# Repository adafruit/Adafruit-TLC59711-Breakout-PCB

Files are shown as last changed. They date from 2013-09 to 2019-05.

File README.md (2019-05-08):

# PCB for the Adafruit TLC59711 12-LED PWM breakout board

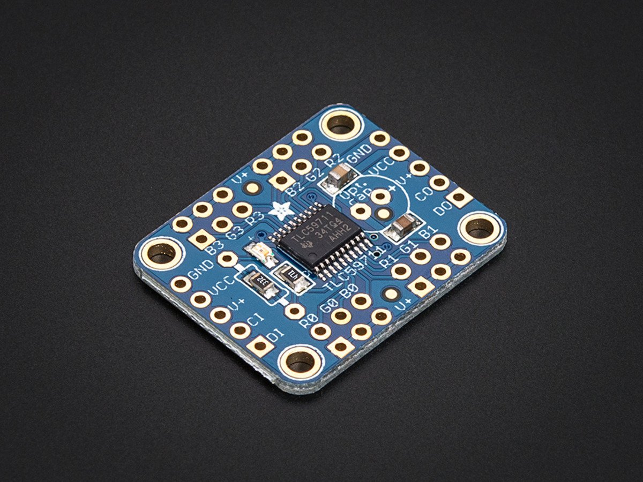
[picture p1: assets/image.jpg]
<a href="http://www.adafruit.com/products/1455"><br/>Click here to purchase one from the Adafruit shop</a>

For all of you out there who want to control 12 channels of PWM, we salute you! We also would like you to check out this breakout board for the TLC59711 PWM driver chip. This chip can control 12 separate channels of 16-bit PWM output. This is the highest-resolution PWM board we've seen! Designed (and ideal) for precision LED control, this board is not good for driving servos. If you need to drive servos, [we have a controller for that over here](http://www.adafruit.com/products/815).

Only two "SPI" pins are required to send data (our Arduino library shows how to to use any digital microcontroller pins). Best of all, the design is completely chainable. As long as there's enough power for all the boards you can chain as many as you'd like, like a little trail of blue PCBs stretching out into the sunset. Each of the 12 outputs are constant-current and open drain. You can drive multiple LEDs in series, with a V+ anode supply of up to 17V. If you want to drive something that requires a digital input, you must use a pullup resistor from the drive pin to your logic level to create the full waveform.

One resistor is used to set the current for each of the outputs, the constant current means that the LED brightness doesn't vary if the power supply dips. We use a 3.3K resistor for about 15mA but you can solder a thru-hole resistor over it if you'd like to change that value. Check the [TLC59711 datasheet](http://www.adafruit.com/datasheets/tlc59711.pdf) for details on resistor-to-current values. There's also a handy on-chip 3.3V regulator which you can use if you need a logic level regulator.

We include a few extras to make this board easy to use: a green power-good LED, four mounting holes and a current-set resistor. A bit of 0.1" header is also included so you can solder it on and plug into a breadboard.

To use: Power V+ with 5-17VDC, and connect ground to the common ground. Then send 3-5V logic SPI data on DIN (data in) and CLK (clock). Our Arduino library will get you started with blinking LEDs, install it and run the example code with the noted pin configuration.

There's a typo in the silkscreen, the second R0 should be R1 - but you knew that already!

## License

Adafruit invests time and resources providing this open source design, 
please support Adafruit and open-source hardware by purchasing 
products from Adafruit!

Designed by Adafruit Industries.  
Creative Commons Attribution, Share-Alike license, check license.txt for more information
All text above must be included in any redistribution

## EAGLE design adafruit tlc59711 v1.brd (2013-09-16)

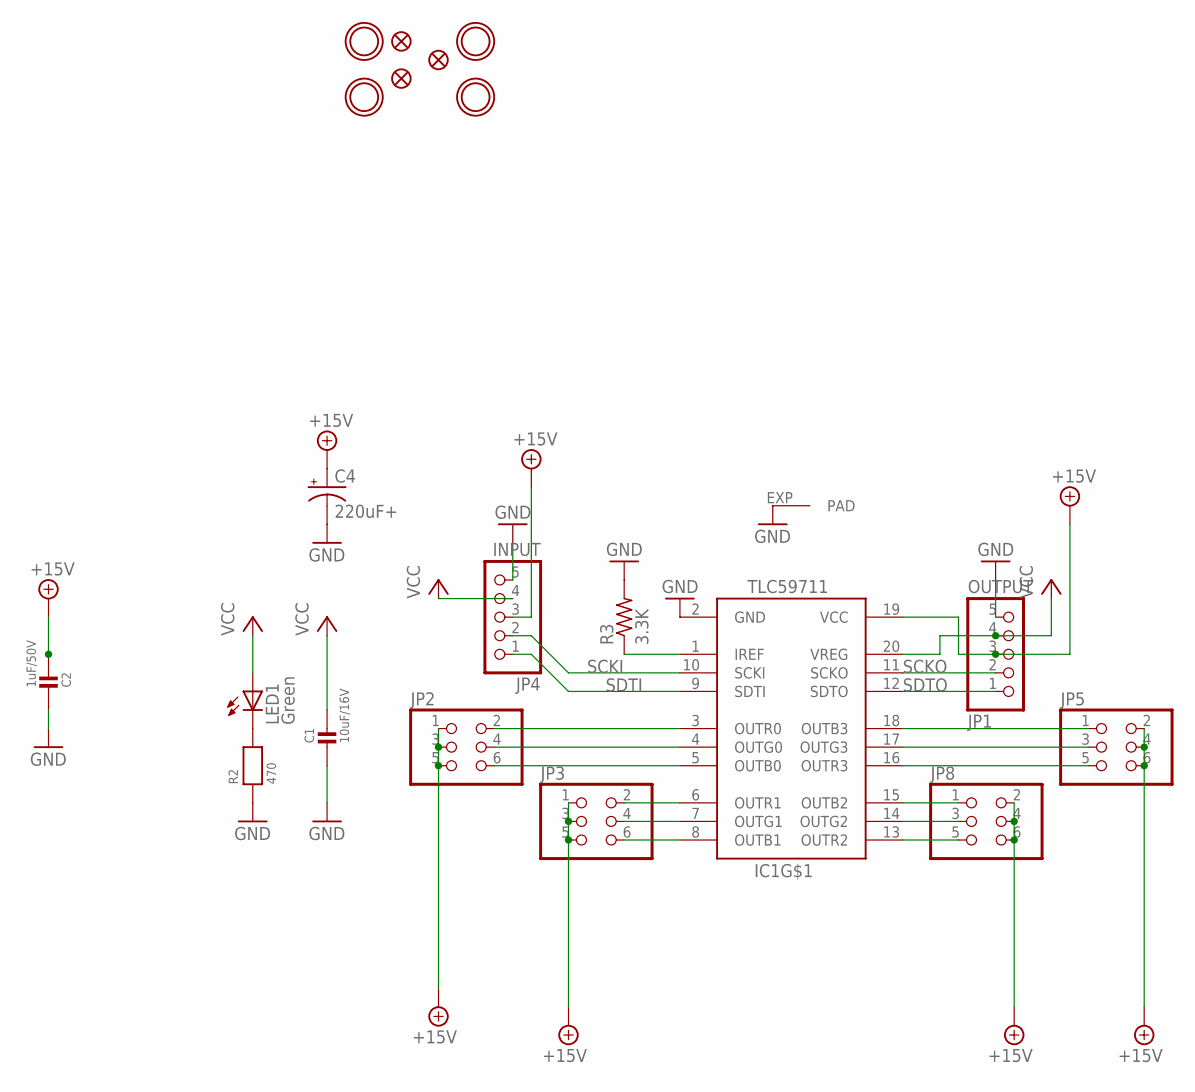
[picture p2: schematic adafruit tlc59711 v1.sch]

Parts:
C1: 10uF/16V; 0805
C2: 1uF/50V; 0805
C4: 220uF+; E2,5-7
FID1, FID2, FID3: FIDUCIAL""; FIDUCIAL_1MM
IC1: TLC59711; HTSSOP20DAP
JP1: OUTPUT; 1X05_ROUND_70
JP2, JP3, JP5, JP8: HEADER-2X3; 2X03_ROUND_70MIL
JP4: INPUT; 1X05_ROUND_70
LED1: Green; CHIP-LED0805
R2: 470; 0805
R3: 3.3K; 0805-THM-7
U$1, U$2, U$3, U$4: MOUNTINGHOLE2.5; MOUNTINGHOLE_2.5_PLATED

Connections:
+15V: C2.1, C4.+, IC1.19 (VCC), JP1.3, JP2.1, JP2.3, JP2.5, JP3.1, JP3.3, JP3.5, JP4.3, JP5.2, JP5.4, JP5.6, JP8.2, JP8.4, JP8.6
GND: C1.2, C2.2, C4.-, IC1.2 (GND), IC1.EXP (PAD), JP1.5, JP4.5, R2.1, R3.2
unnamed: LED1.C, R2.2
unnamed: IC1.1 (IREF), R3.1
unnamed: IC1.3 (OUTR0), JP2.2
unnamed: IC1.4 (OUTG0), JP2.4
unnamed: IC1.5 (OUTB0), JP2.6
unnamed: IC1.6 (OUTR1), JP3.2
unnamed: IC1.7 (OUTG1), JP3.4
unnamed: IC1.8 (OUTB1), JP3.6
unnamed: IC1.15 (OUTB2), JP8.1
unnamed: IC1.14 (OUTG2), JP8.3
unnamed: IC1.13 (OUTR2), JP8.5
unnamed: IC1.18 (OUTB3), JP5.1
unnamed: IC1.17 (OUTG3), JP5.3
unnamed: IC1.16 (OUTR3), JP5.5
SCKI: IC1.10 (SCKI), JP4.2
SCKO: IC1.11 (SCKO), JP1.2
SDTI: IC1.9 (SDTI), JP4.1
SDTO: IC1.12 (SDTO), JP1.1
VCC: C1.1, IC1.20 (VREG), JP1.4, JP4.4, LED1.A

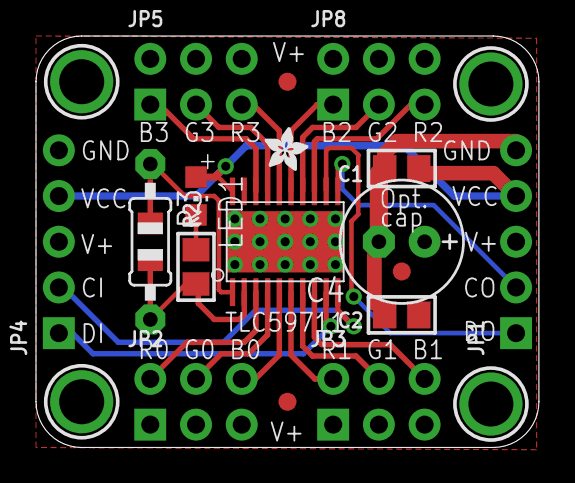
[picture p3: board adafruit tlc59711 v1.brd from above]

Board: 2 copper layers, 27.9 x 22.9 mm, 22 parts (1 on the bottom side), 21 nets.

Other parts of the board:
U$7: ADAFRUIT_2.5MM
U$8: ADAFRUIT_3.5MM

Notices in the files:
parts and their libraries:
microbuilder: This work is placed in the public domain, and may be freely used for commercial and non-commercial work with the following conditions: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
